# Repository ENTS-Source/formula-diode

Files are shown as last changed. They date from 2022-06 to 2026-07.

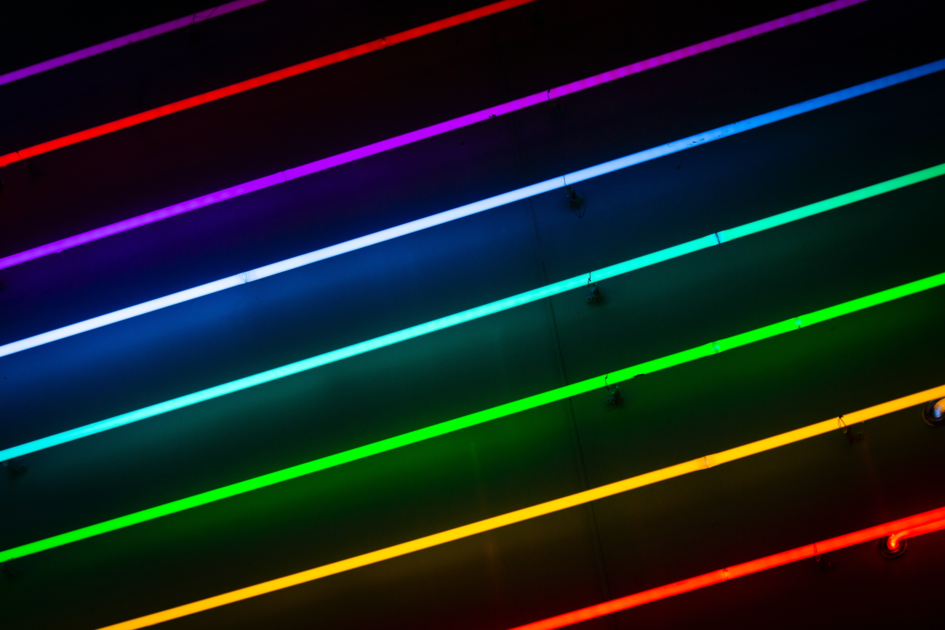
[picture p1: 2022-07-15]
pi-scoreboard/src/components/main/bg.jpg

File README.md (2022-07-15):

# led-race
Race each other on an LED strip, using an ESP8266

## Arduino libraries

* Regexp
* AsyncHTTPRequest_Generic
* ESP8266WiFi
* WiFiManager

## Running scoreboard

`npm install && npm start` in `pi-scoreboard`

Screenshot:


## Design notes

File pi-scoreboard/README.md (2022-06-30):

Created using https://www.electronforge.io/guides/framework-integration/react-with-typescript as a guide.

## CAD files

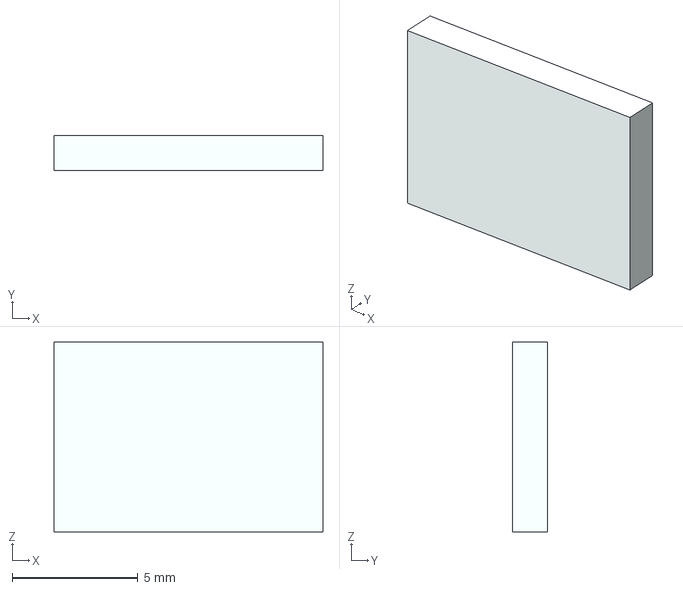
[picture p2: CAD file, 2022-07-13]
boards/kicad/Foorprints/IC_Microchip_MCP1825S-3302E_AB/eec.models/Microchip_-_MCP1825S-3302E/AB.step
10.7 x 1.40 x 7.55 mm

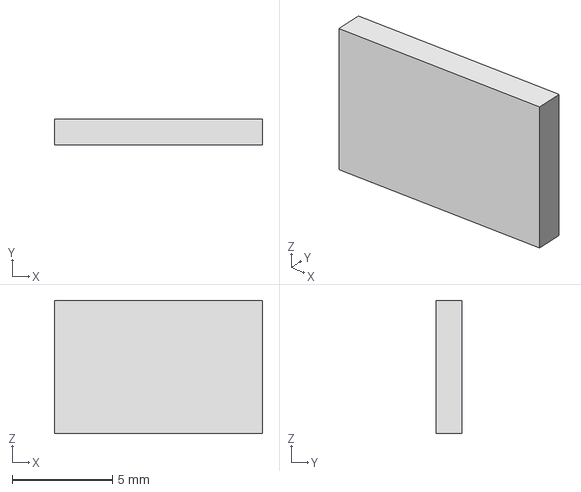
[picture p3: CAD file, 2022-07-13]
boards/kicad/Foorprints/IC_STMicroelectronics_LD1117V33C/eec.models/STMicroelectronics_-_LD1117V33C.step
10.4 x 1.30 x 6.65 mm

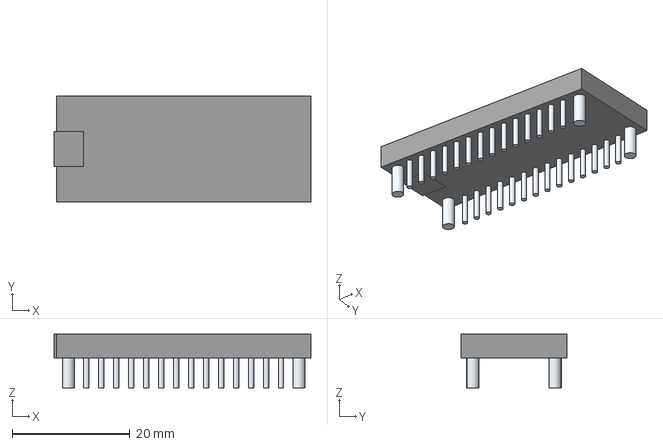
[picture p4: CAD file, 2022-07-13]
boards/kicad/Foorprints/LIB_Metro/2590/3D/2590.stp
43.6 x 18.0 x 9.10 mm
Leads x 32

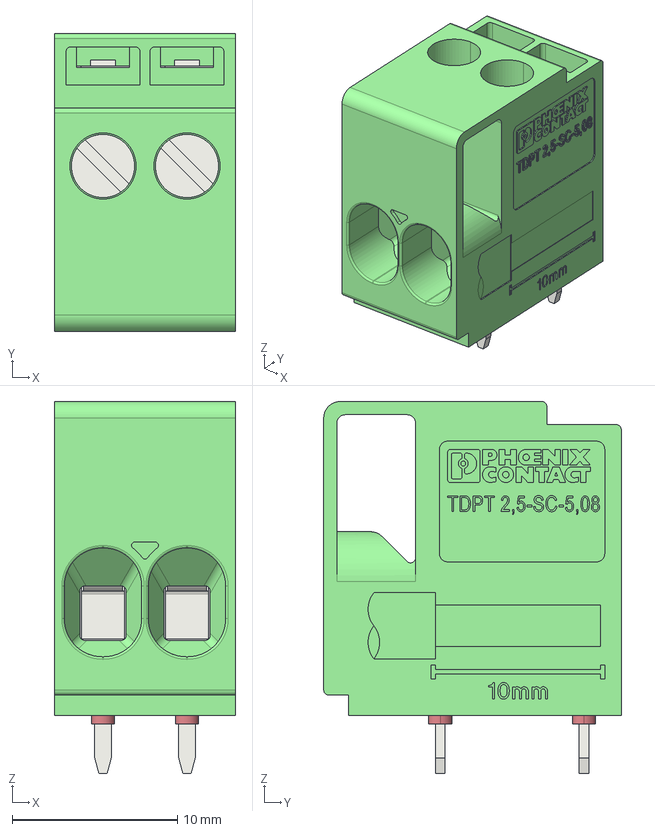
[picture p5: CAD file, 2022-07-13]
boards/kicad/Foorprints/LIB_1017491/1017491/3D/1017491.stp
11.0 x 18.0 x 22.5 mm
Bohrloch x 4
AC_MKDSN_2_5_Laengsschlitz x 2
KK_TDPT_Klemmhuelse x 2
LP_TDPT_2_5_SC_current_bar x 2
TDPT-2.5-2-SC-5.08-GEH

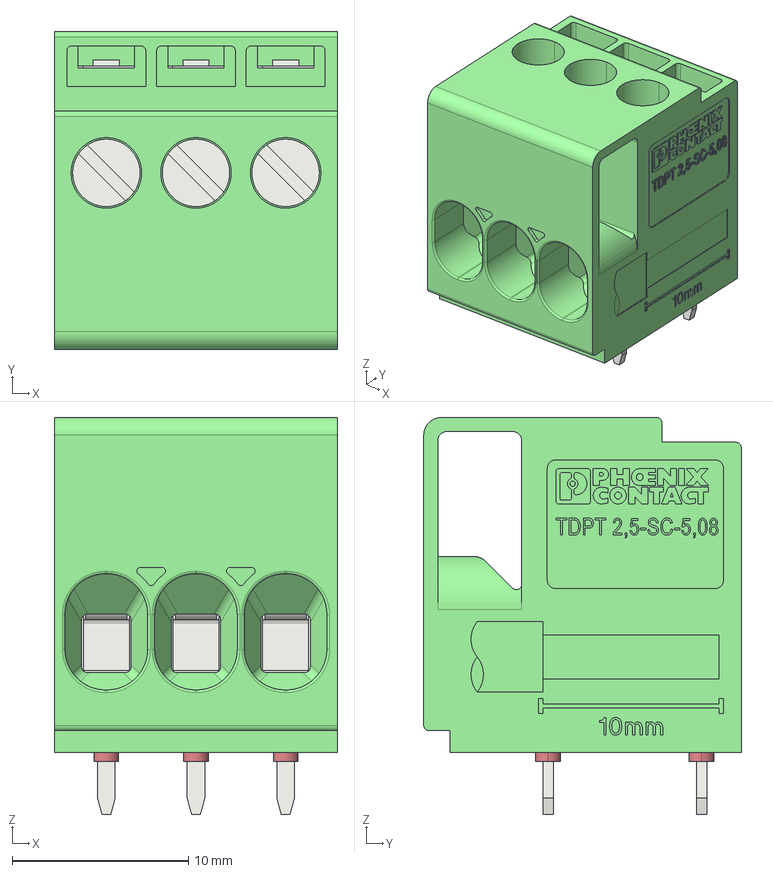
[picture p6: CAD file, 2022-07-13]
boards/kicad/Foorprints/LIB_1017492/1017492/3D/1017492.stp
16.0 x 18.0 x 22.5 mm
Bohrloch x 6
AC_MKDSN_2_5_Laengsschlitz x 3
KK_TDPT_Klemmhuelse x 3
LP_TDPT_2_5_SC_current_bar x 3
TDPT-2.5-3-SC-5.08-GEH

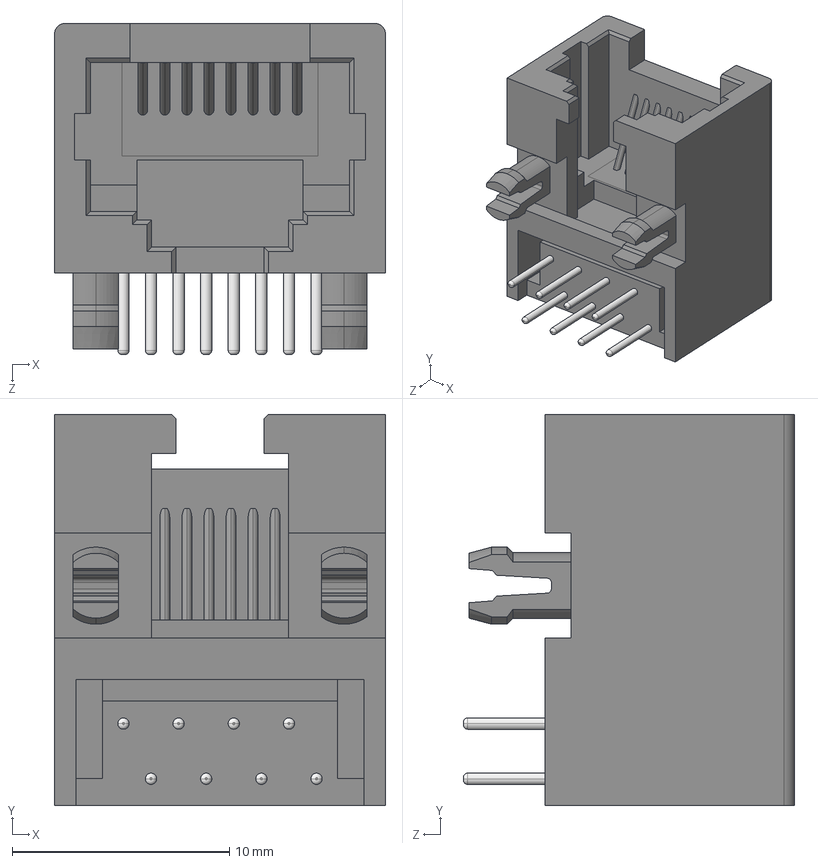
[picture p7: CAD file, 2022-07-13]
boards/kicad/Foorprints/LIB_54601-908WPLF/54601-908WPLF/3D/54601-908WPLF.stp
15.2 x 18.0 x 15.2 mm

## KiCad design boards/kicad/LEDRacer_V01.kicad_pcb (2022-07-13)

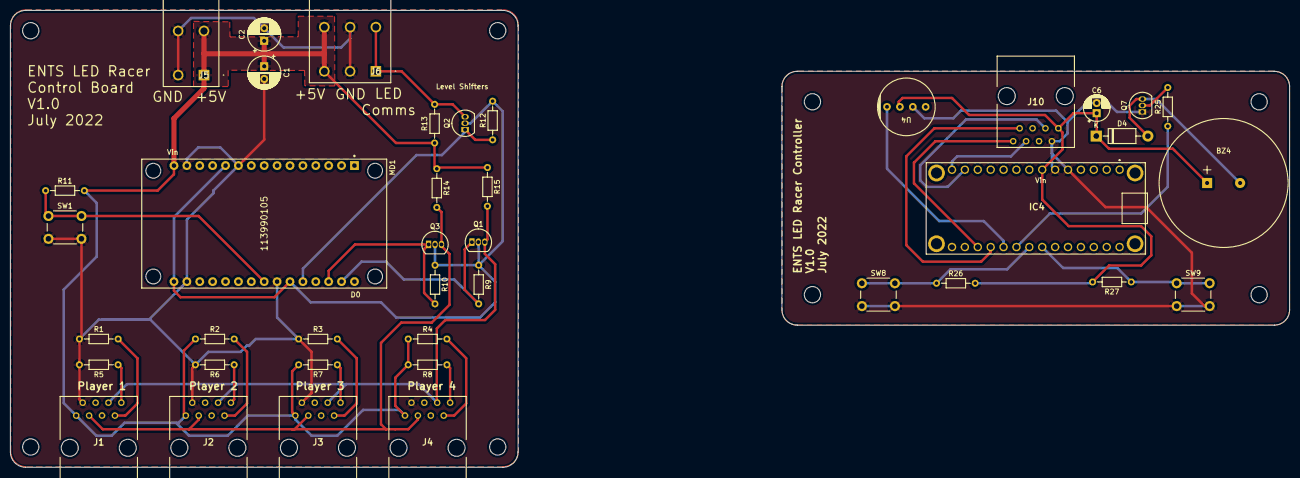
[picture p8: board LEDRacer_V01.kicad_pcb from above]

Board: 2 copper layers, 252.0 x 90.0 mm, 40 parts (0 on the bottom side), 28 nets.

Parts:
BZ4: Buzzer; WT1209
C1, C2: C_Polarized; CP_Radial_D6.3mm_P2.50mm
C6: C_Polarized; CP_Radial_D5.0mm_P2.00mm
D4: D; D_DO-41_SOD81_P10.16mm_Horizontal
IC4: 2590
J1, J2, J3, J4, J10: 54601-908WPLF; 54601908WPLF
J5: 1017491
J6: 1017492
MD1: 113990105; Seeed_Studio-113990105-MFG
Q1, Q2, Q3: TN0104N3-G; TO-92_Inline
Q7: Q_NPN_EBC; TO-92_Inline
R1, R2, R3, R4, R5, R6, R7, R8: 1k; R_Axial_DIN0204_L3.6mm_D1.6mm_P7.62mm_Horizontal
R9, R10, R14, R15: 4.7K; R_Axial_DIN0204_L3.6mm_D1.6mm_P7.62mm_Horizontal
R11, R12, R13, R26, R27: 4.7k; R_Axial_DIN0204_L3.6mm_D1.6mm_P7.62mm_Horizontal
R25: 1.5k; R_Axial_DIN0204_L3.6mm_D1.6mm_P7.62mm_Horizontal
SW1, SW8, SW9: SW_Push; SW_PUSH_6mm
U4: COM-12986; COM12986

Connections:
+3V3: MD1.11 (3V3), MD1.16 (3V3), MD1.25 (3V3), Q1.2 (G), Q2.2 (G), Q3.2 (G), R9.1, R10.1, R12.2
+5V: BZ4.1 (-), C1.1, C2.1, C6.1, D4.1 (K), IC4.7 (VIN), J1.1, J2.1, J3.1, J4.1, J5.1 (1.1), J5.2 (1.2), J6.5 (3.1), J6.6 (3.2), J10.1, MD1.15 (VIN), R2.1, R4.1, R7.2, R8.2, R11.2, R13.2, R14.1, R15.1, R26.2, R27.2, U4.2 (VDD)
/Button: MD1.23 (D5), R11.1, SW1.1
/Controller3/Button_1: IC4.21 (I/O_6), R26.1, SW8.1
/Controller3/Button_2: IC4.22 (I/O_7), R27.1, SW9.1
/Controller3/Buzzer: IC4.20 (I/O_5), R25.1
/Controller3/ID_1: IC4.18 (I/O_3), J10.7
/Controller3/ID_2: IC4.17 (I/O_2), J10.8
/Controller3/LED_Sig: IC4.19 (I/O_4), U4.1 (DIN)
/Controller3/SCL_HV: IC4.14 (A5), J10.6
/Controller3/SDA_HV: IC4.13 (A4), J10.3
/LED_COMM_HV: J6.1 (1.1), J6.2 (1.2), Q2.3 (D), R13.1
/LED_COMM_LV: MD1.26 (D4), Q2.1 (S), R12.1
/SCL_HV: J1.6, J2.6, J3.6, J4.6, Q1.3 (D), R15.2
/SCL_LV: MD1.29 (D1), Q1.1 (S), R9.2
/SDA_HV: J1.3, J2.3, J3.3, J4.3, Q3.3 (D), R14.2
/SDA_LV: MD1.28 (D2), Q3.1 (S), R10.2
GND: C1.2, C2.2, C6.2, IC4.5 (GND_1), IC4.6 (GND_2), J1.2, J2.2, J3.2, J4.2, J5.3 (2.1), J5.4 (2.2), J6.3 (2.1), J6.4 (2.2), J10.2, MD1.10 (GND), MD1.14 (GND), MD1.17 (GND), MD1.24 (GND), Q7.1 (E), R1.1, R3.1, R5.2, R6.2, SW1.2, SW8.2, SW9.2, U4.3 (VSS)
unnamed: BZ4.2 (+), D4.2 (A), Q7.3 (C)
unnamed: J1.7, R1.2
unnamed: J1.8, R5.1
unnamed: J2.7, R2.2
unnamed: J2.8, R6.1
unnamed: J3.7, R3.2
unnamed: J3.8, R7.1
unnamed: J4.7, R4.2
unnamed: J4.8, R8.1
unnamed: Q7.2 (B), R25.2

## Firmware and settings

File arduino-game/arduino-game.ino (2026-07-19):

#include <FastLED.h>
#include <EEPROM.h>
#include <Regexp.h>
#include <WiFiManager.h>
#include <Wire.h>
#include <ArduinoOTA.h>

// NodeMCU / ESP8266

/*
TODO:
- Fix NO_SCOREBOARD to actually work (also, make it configurable via web)
- Add world editor (ideally via web: add feature button, left+right to move down the track, up+down to make bigger and smaller)
- Easy/Medium/Hard levels (switchable from front button?)
- Make LED strip length web config (with visual so it can be easily measured)
- Try to remove I2C dependency to deal with PCB flexing issues
- Interrupt screensaver with controller buttons? (undecided)
*/

#define BTN_PIN D5 // TODO: Will we need to support multiple buttons?
#define SDA_PIN D2
#define SCL_PIN D1
#define WIRE_SPEED 100000
#define I2C_PLAYERS 4
#define STRIP_COUNT 1 // TODO: Support this being 2 (using logical strips)
#define MAX_LAPS 3 // TODO: Config val
#define LED_STRIP_PIN D4
//#define STRIP_LENGTH 325
//#define STRIP_LENGTH 385
#define MIN_STRIP_LENGTH 40
#define MAX_STRIP_LENGTH 600
#define WINNER_SHOWN_MS 2500
#define INIT_PLAYER_LENGTH 3
#define PHYSICS_ACCL 0.125 // Velocity added per button press
#define PHYSICS_FRICTION 0.017
#define GRAVITY_EFFECT 0.007
#define SPEED_BOOST_FACTOR 0.3
#define TAR_TRAP_FRICTION 0.18
#define TAR_TRAP_ACCL 0.06
#define CATCHUP_BOOST_ACCL 0.20
#define PHYSICS_MAX_VELOCITY 800000
#define PHYSICS_MIN_VELOCITY -2
#define PHYSICS_MS 5 // Time between physics checks
#define SCREENSAVER_WAIT_MS 120000 // 2 minutes
#define GAME_TIMEOUT_MS 30000 // 30 seconds
#define COUNT_MODE_WAIT_MS 5000 // 5 seconds
#define AUTO_RAND_MIN 0
#define AUTO_RAND_MAX 1000
#define AUTO_THRESHOLD 50 // Note: debounce is typically 10ms, so 15/1000 is essentially saying "every 15ms, trigger"
#define AUTO_PRESSES_PER 1
#define AUTO_PLAYERS 2
#define RENDER_INTERVAL 14

#define NOT_CONNECTED_PIN D6
#define CONF_EEPROM_SIZE 512
#define CONF_LENGTH_ADDR 128 // start a bit high to give wifimanager some room
#define BTN_OPEN HIGH
#define BTN_CLOSED LOW
#define BTN_DEBOUNCE_MS 10
#define I2C_PLAYER_START 0 // address
#define TOHOST_LENGTH 2  // btn 1 presses & btn 2 presses, 2 bytes
#define FROMHOST_ASSIGN 0x10
#define FROMHOST_RESET 0x11
#define TRAFFIC_START 7 // address; +1 from bottom, for aesthetics. Must be at least 6
#define NO_WINNER -1
#define NW_STATUS_LED 4
#define WIRE_PING_MS 5000
#define GRAVITY_ENABLED B00000001
#define SPEED_BOOST_ENABLED B00000100
#define SLOPE_FORWARD B00000010
#define SLOPE_BACKWARD B00000000 // inverse of forward
#define TAR_TRAP_ENABLED B00001000

int featuresRange[][3] = {
  // 2022
//  {272, 38, GRAVITY_ENABLED | SLOPE_BACKWARD},
//  {310, 35, GRAVITY_ENABLED | SLOPE_FORWARD},

  // 2025-1
//  {265, 5, SPEED_BOOST_ENABLED},
//  {45, 5, SPEED_BOOST_ENABLED},

  // 2025-2
  {249, 5, TAR_TRAP_ENABLED},
  {307, 5, SPEED_BOOST_ENABLED},
  {119, 5, SPEED_BOOST_ENABLED},
//  {11, 15, SPEED_BOOST_ENABLED},
};

struct PlayerState {
  float velocity;
  float position;
  int location; // int position
  int length;
  CRGB color;

  int unhandledPresses;
  long lastPhysics;

  long finishMs;
  long lastLapFinishMs;
  bool isConnected;
};

int stripLength = MIN_STRIP_LENGTH;
CRGB leds[MAX_STRIP_LENGTH * STRIP_COUNT];
byte stripMap[MAX_STRIP_LENGTH * STRIP_COUNT];
long startTimeMs = 0;
long lightsStartMs = 0;
long endMs = 0;
long lastGameEnd = 0;
int winnerNum = NO_WINNER;
bool inGame = false;
bool isAutomatedGame = false;
bool btnDownTrigger = false;
bool btnUpTrigger = false;
bool btnPressed = false;
long lastWireScan = 0;
long lastRender = 0;
long lastPress = 0;
bool countingMode = false;
long countModeStartTimeout = 0;
long lastCountModeChange = 0;

CRGB TRAFFIC_RED = CRGB(255, 0, 0);
CRGB TRAFFIC_YELLOW = CRGB(239, 83, 0);
CRGB TRAFFIC_GREEN = CRGB(0, 132, 5);

CRGB SPEED_BOOST_COLOR = CRGB(255, 170, 0);
CRGB TAR_TRAP_COLOR = CRGB(46, 0, 74);

CRGB colors[I2C_PLAYERS] = {
  CRGB::Blue,
  CRGB::Red,
  CRGB::Green,
  CRGB::Orange,
};
PlayerState players[I2C_PLAYERS] = {
  PlayerState{},
  PlayerState{},
  PlayerState{},
  PlayerState{},
};

void setup() {
  randomSeed(analogRead(NOT_CONNECTED_PIN));
  Serial.begin(115200);
  gnetSetup();
  confSetup();
  ledSetup(false);
  trakSetup();
  netSetup();

  for (int i = 0; i < I2C_PLAYERS; i++) {
    playerReset(players[i]);
    players[i].color = colors[i];
    Serial.print("Player ");
    Serial.print(i);
    Serial.print(" is ");
    printColor(colors[i]);
    Serial.println();
  }

  gnetScan();
  gnetResetAll();
  updatePlayerIds();
}

void loop() {
  ArduinoOTA.handle();

  bool doReset = trakUpdate();
  if (doReset || ((!inGame || isAutomatedGame) && lightsStartMs == 0 && (millis() - lastWireScan) > WIRE_PING_MS)) {
    lastWireScan = millis();
    gnetScan();
    gnetResetAll();
    updatePlayerIds();
  }
  gnetUpdate();
  if (countingMode) {
    int newLength = stripLength;
    lastGameEnd = millis(); // avoid screensaver
    newLength += players[0].unhandledPresses;
    newLength -= players[1].unhandledPresses;
    // Serial.print("Strip length: ");
    // Serial.print(stripLength);
    // Serial.print("     New strip length: ");
    // Serial.print(newLength);
    // Serial.print("     player0 presses: ");
    // Serial.print(players[0].unhandledPresses);
    // Serial.print("     player1 presses: ");
    // Serial.println(players[1].unhandledPresses);
    players[0].unhandledPresses = 0;
    players[1].unhandledPresses = 0;
    if (newLength != stripLength) {
      confWriteInt(CONF_LENGTH_ADDR, newLength);
      confWrite();
      ledSetup(true); // this will clear the old length and new length for us
      trakCountStrip();
    }
    if (btnPressed && (millis() - lastCountModeChange) > COUNT_MODE_WAIT_MS) {
      Serial.println("Exiting counting mode");
      countingMode = false;
      countModeStartTimeout = millis();
      lastCountModeChange = millis();
    }
  } else if (!inGame && !countingMode && (millis() - lastCountModeChange) > COUNT_MODE_WAIT_MS) {
    if (countModeStartTimeout == 0 && btnDownTrigger) {
      Serial.println("Starting count mode wait");
      countModeStartTimeout = millis();
    } else if (!btnPressed) {
      // Serial.println("Resetting count mode wait");
      countModeStartTimeout = 0;
    } else if ((millis() - countModeStartTimeout) > COUNT_MODE_WAIT_MS) {
      Serial.println("Entering counting mode");
      countingMode = true;
      lastCountModeChange = millis();
    }
  }
}

void updatePlayerIds() {
  for (int i = 0; i < I2C_PLAYERS; i++) {
    gnetUpdateColor(i, players[i].color.r, players[i].color.g, players[i].color.b);
  }
}

void ledSetup(bool andClear) {
  if (andClear) {
    trakClear(); // clear old size
    trakRender();
  }

  stripLength = confReadInt(CONF_LENGTH_ADDR);
  if (stripLength <= MIN_STRIP_LENGTH) {
    stripLength = MIN_STRIP_LENGTH;
  }
  if (stripLength > MAX_STRIP_LENGTH) { // also avoids empty EEPROM having 0xFFFF values (65535)
    stripLength = MAX_STRIP_LENGTH;
  }
  Serial.print("Strip length: ");
  Serial.println(stripLength);
  
  if (andClear) {
    trakClear(); // clear new size (if larger/different)
    trakRender();
  }

  for (int i = 0; i < (stripLength * STRIP_COUNT); i++) {
    stripMap[i] = 0;
  }

  int featureRows = sizeof(featuresRange) / sizeof(featuresRange[0]);
  for (int i = 0; i < featureRows; i++) {
    int startIdx = featuresRange[i][0];
    int lengthIdx = featuresRange[i][1];
    byte flags = featuresRange[i][2];
    for (int j = startIdx; j <= (startIdx + lengthIdx); j++) {
      if (j > (stripLength * STRIP_COUNT)) {
        continue;
      }
      stripMap[j] = flags;
    }
  }
  
  trakSetupForDrawPlayers();
}

// ---------------------------------------------------------------
// ---- PLAYERS
// ===============================================================

void playerPhysics(PlayerState &player) {
  if (!player.isConnected) {
    return;
  }
  if (player.finishMs > 0) {
    return; // they're done the race
  }

  // Check if player is behind
  bool behind = false;
  uint8_t numFinished = 0;
  for (int i = 0; i < I2C_PLAYERS; i++) {
    PlayerState pl = players[i];
    if (pl.finishMs > 0 || !pl.isConnected) {
      numFinished++;
      continue; // skip players that are already done
    }
    int diff = player.location - pl.location;
    if (diff <= (-1 * stripLength)) { // 1 full lap behind
      behind = true;
    }
  }
  // Serial.print("Behind? ");
  // Serial.print(behind);
  if (!behind && (I2C_PLAYERS - numFinished) == 1) {
    behind = true;
  }
  // Serial.print("   Still? ");
  // Serial.println(behind);

  int relPos = (player.location + player.length) % stripLength;
  bool tarTrap = (stripMap[relPos] & TAR_TRAP_ENABLED) != 0;
  for (int i = 0; i < player.unhandledPresses; i++) {
    if (behind) {
      player.velocity += CATCHUP_BOOST_ACCL;
    }
    lastPress = millis();
    if (tarTrap) {
      player.velocity += TAR_TRAP_ACCL;
    } else {
      player.velocity += PHYSICS_ACCL;
    }
  }
  player.unhandledPresses = 0;

  if ((millis() - player.lastPhysics) < PHYSICS_MS) {
    return; // done with physics for now
  }
  player.lastPhysics = millis();

  if (player.velocity > PHYSICS_MAX_VELOCITY) {
    player.velocity = PHYSICS_MAX_VELOCITY;
  }

  // Move vehicle
  float friction = PHYSICS_FRICTION;
  if (tarTrap) {
    friction = TAR_TRAP_FRICTION;
  }
  player.velocity -= player.velocity * friction;
  if (player.velocity < PHYSICS_MIN_VELOCITY) {
    player.velocity = PHYSICS_MIN_VELOCITY;
  }
  player.position += player.velocity;
  player.location = round(player.position); // int location

  // Gravity, front wheel drive
  relPos = (player.location + player.length) % stripLength;
  if ((stripMap[relPos] & GRAVITY_ENABLED) != 0) {
    float effect = GRAVITY_EFFECT;
    if ((stripMap[relPos] & SLOPE_FORWARD) == 0) {
      // means we're sloping backwards
      effect = effect * -1;
    }
    player.velocity += effect;
    player.position += player.velocity;
  }
  if ((stripMap[relPos] & SPEED_BOOST_ENABLED) != 0) {
    player.velocity += SPEED_BOOST_FACTOR;
    player.position += player.velocity;
//    stripMap[relPos] = (stripMap[relPos] & ~SPEED_BOOST_ENABLED);
  }

  // Last minute check on position
  if (player.position < 0) {
    player.position = 0;
  }
  player.location = round(player.position);
}

void playerReset(PlayerState &player) {
  player.length = INIT_PLAYER_LENGTH;
  player.position = 0;
  player.location = 0;
  player.velocity = 0;
  player.finishMs = 0;
  player.lastLapFinishMs = 0;
  player.unhandledPresses = 0;
}

// ---------------------------------------------------------------
// ---- TRACK
// ===============================================================

void trakSetup() {
  trakClear();
  trakRender();
  FastLED.addLeds<WS2812B, LED_STRIP_PIN, GRB>(leds, MAX_STRIP_LENGTH);
}

// Primary loop
// ======================================

bool trakUpdate() {
  bool shouldReset = false;
  btnUpdate();

  if (countingMode) {
    return shouldReset; // nothing to do except update the button
  }

  trakClear();

  if (!inGame) {
    if (winnerNum != NO_WINNER) {
      long timeDiff = millis() - endMs;
      if (timeDiff < WINNER_SHOWN_MS) {
        trakDrawWinner();
      } else {
        winnerNum = NO_WINNER;
        endMs = 0;
        lastGameEnd = millis();

        if (isAutomatedGame) {
          lastGameEnd = 0; // allow another automated game to start right away
          shouldReset = true;
        }
      }
    } else if (lightsStartMs > 0) {
      if (isAutomatedGame) {
        leds[TRAFFIC_START + 6] = CRGB::Purple;
        leds[TRAFFIC_START + 5] = CRGB::Purple;
      }
      
      leds[TRAFFIC_START - 0] = TRAFFIC_RED;
      leds[TRAFFIC_START - 1] = TRAFFIC_RED;

      if ((millis() - lightsStartMs) >= 1000) {
        leds[TRAFFIC_START - 2] = TRAFFIC_YELLOW;
        leds[TRAFFIC_START - 3] = TRAFFIC_YELLOW;
      }

      if ((millis() - lightsStartMs) >= 2000) {
        for (int i = 0; i < 6; i++) {
          leds[TRAFFIC_START - i] = TRAFFIC_GREEN;
        }
      }

      if ((millis() - lightsStartMs) >= 2400) {
        shouldReset = true;
        inGame = true;
        lightsStartMs = 0;
        startTimeMs = millis();

        int nPlayers = 0;
        for (int i = 0; i < I2C_PLAYERS; i++) {
          playerReset(players[i]);
          if (players[i].isConnected) {
            nPlayers++;
          }
        }
      }
    } else if ((millis() - lastGameEnd) > SCREENSAVER_WAIT_MS) {
      isAutomatedGame = true;
      Serial.println("Screensaver");
      
      lightsStartMs = millis();
      shouldReset = true;
    }
  } else {
    trakUpdatePlayers();
    trakDrawBoosts();
    trakDrawPlayers();
    if (!isAutomatedGame && (millis() - lastPress) > GAME_TIMEOUT_MS) {
      isAutomatedGame = true;
      lastGameEnd = 0; // enter screensaver immediately
    }
  }
  
  if (btnUpTrigger) {
    // Interrupt current game and start a new one
    isAutomatedGame = false;    
    lightsStartMs = millis();
    shouldReset = true;
    lastPress = millis();
    inGame = false;
  }

  if ((millis() - lastRender) >= RENDER_INTERVAL) {
    lastRender = millis();
    trakRender();
  }
  return shouldReset;
}

// Game functions
// ======================================

void trakUpdatePlayers() {
  bool allDone = true;
  for (int i = 0; i < I2C_PLAYERS; i++) {
    if (isAutomatedGame) {
      players[i].isConnected = (i < AUTO_PLAYERS);
    }
    
    if (!players[i].isConnected) {
      continue;
    }
    if (players[i].finishMs > 0) {
      continue; // already finished all laps (don't adjust lap times)
    }

    if (isAutomatedGame && random(AUTO_RAND_MIN, AUTO_RAND_MAX) <= AUTO_THRESHOLD) {
      players[i].unhandledPresses += AUTO_PRESSES_PER;
    }

    int oldLaps = players[i].location / stripLength;
    playerPhysics(players[i]);
    int newLaps = players[i].location / stripLength;

    if (newLaps != oldLaps) {
      long lastLapMs = players[i].lastLapFinishMs;
      if (lastLapMs == 0) {
        lastLapMs = startTimeMs;
      }
      long lapTime = millis();
      players[i].lastLapFinishMs = lapTime;
    }

    if ((players[i].location / stripLength) >= MAX_LAPS) {
      players[i].finishMs = millis();
    }

    allDone = allDone && (players[i].finishMs > 0);
  }

  if (allDone) {
    inGame = false;
    endMs = millis();
    winnerNum = NO_WINNER;
    for (int i = 0; i < I2C_PLAYERS; i++) {
      if (!players[i].isConnected) {
        continue;
      }
      if (winnerNum == NO_WINNER || players[winnerNum].finishMs > players[i].finishMs) {
        winnerNum = i;
      }
    }
  }
}

// Render functions
// ======================================

void trakClear() {
  for (int i = 0; i < (stripLength * STRIP_COUNT); i++) {
    leds[i] = CRGB::Black;
  }
}

void trakCountStrip() {
  for (int i = 0; i < (stripLength * STRIP_COUNT); i++) {
    leds[i] = SPEED_BOOST_COLOR;
  }
  trakRender();
}

void trakDrawWinner() {
  for (int i = 0; i < (stripLength * STRIP_COUNT); i++) {
    leds[i] = players[winnerNum].color;
  }
}

void printColor(CRGB color) {
  Serial.print(color.r);
  Serial.print(",");
  Serial.print(color.g);
  Serial.print(",");
  Serial.print(color.b);
}

uint8_t* positionMap = nullptr;
bool* didTrapOverlay = nullptr;

void trakSetupForDrawPlayers() {
  if (positionMap != nullptr) {
    delete[] positionMap;
    positionMap = nullptr;
  }
  if (didTrapOverlay != nullptr) {
    delete[] didTrapOverlay;
    didTrapOverlay = nullptr;
  }
  positionMap = new uint8_t[stripLength * STRIP_COUNT];
  didTrapOverlay = new bool[stripLength * STRIP_COUNT];
}

void trakDrawPlayers() {
  // Figure out where each player is an render them into the LEDs
  for (int i = 0; i < (stripLength * STRIP_COUNT); i++) {
    positionMap[i] = 0;
    didTrapOverlay[i] = false;
  }
  for (int i = 0; i < I2C_PLAYERS; i++) {
    if (!players[i].isConnected) {
      continue;
    }
    if (players[i].finishMs > 0) {
      continue; // don't render: they're done
    }

    int startPos = players[i].location % stripLength;
    for (int j = 0; j < players[i].length; j++) {
      int targetLoc = startPos + j;
      int maxStripPos = stripLength * STRIP_COUNT;
      if (targetLoc >= maxStripPos) {
        targetLoc = (targetLoc - maxStripPos); // overrun
      }
      positionMap[targetLoc]++;
//      Serial.print("@@ Draw ");
//      Serial.print(targetLoc);
//      Serial.print(" curr:");
//      printColor(leds[targetLoc]);
//      Serial.print(" plyr:");
//      printColor(players[i].color);
        if ((stripMap[targetLoc] & TAR_TRAP_ENABLED) != 0 && !didTrapOverlay[targetLoc]) {
          leds[targetLoc] = CRGB(0, 0, 0);
          didTrapOverlay[targetLoc] = true;
        }
        leds[targetLoc] = CRGB(
          leds[targetLoc].r + players[i].color.r,
          leds[targetLoc].g + players[i].color.g,
          leds[targetLoc].b + players[i].color.b
        );
//      Serial.print(" res:");
//      printColor(leds[targetLoc]);
//      Serial.println();
    }
  }

  // Mix colors
  for (int i = 0; i < (stripLength * STRIP_COUNT); i++) {
    uint8_t mapHeight = positionMap[i];
    if (mapHeight > 1) {
      leds[i] = CRGB(
        leds[i].r / mapHeight,
        leds[i].g / mapHeight,
        leds[i].b / mapHeight
      );
    }
  }
}

void trakDrawBoosts() {
  for (int i = 0; i < (stripLength * STRIP_COUNT); i++) {
    if ((stripMap[i] & SPEED_BOOST_ENABLED) != 0) {
      leds[i] = SPEED_BOOST_COLOR;
    }
    if ((stripMap[i] & TAR_TRAP_ENABLED) != 0) {
      leds[i] = TAR_TRAP_COLOR;
    }
  }
}

void trakRender() {
  FastLED.show();
}

// ---------------------------------------------------------------
// ---- GAME NET
// ===============================================================

void gnetSetup() {
  Wire.setClock(WIRE_SPEED);
  Wire.begin(SDA_PIN, SCL_PIN);
}

void gnetUpdate() {
  for (int i = 0; i < I2C_PLAYERS; i++) {
    if (!players[i].isConnected) {
      continue;
    }

    byte addr = I2C_PLAYER_START + i;
    Wire.requestFrom(addr, TOHOST_LENGTH);
    byte pos = 0;
    while (Wire.available()) {
      byte b = Wire.read();
      if (pos >= TOHOST_LENGTH) {
        continue;
      }

      if (pos == 0) {
        players[i].unhandledPresses += b;
      } else if (pos == 1) {
        // Secondary button not used
      }

      pos++;
    }
  }
}

void gnetScan() {
  for (int i = 0; i < I2C_PLAYERS; i++) {
    byte addr = I2C_PLAYER_START + i;
    Wire.beginTransmission(addr);
    byte err = Wire.endTransmission();
    if (err == 0) {
      Serial.print(i);
      Serial.println(" is connected to I2C");
      players[i].isConnected = true;
    } else {
      Serial.print(i);
      Serial.print(" failed to connect on I2C with error ");
      Serial.println(err);
      players[i].isConnected = false;
    }
  }
}

void gnetUpdateColor(int playerNum, byte r, byte g, byte b) {
  if (!players[playerNum].isConnected) {
    return;
  }

  Wire.beginTransmission(I2C_PLAYER_START + playerNum);
  byte msg[4] = {FROMHOST_ASSIGN, r, g, b};
  Wire.write(msg, 4);
  Wire.endTransmission();
}

void gnetResetController(int playerNum) {
  if (!players[playerNum].isConnected) {
    return;
  }

  Wire.beginTransmission(I2C_PLAYER_START + playerNum);
  byte msg[1] = {FROMHOST_RESET};
  Wire.write(msg, 1);
  Wire.endTransmission();
}

void gnetResetAll() {
  for (int i = 0; i < I2C_PLAYERS; i++) {
    gnetResetController(i);
  }
}

// ---------------------------------------------------------------
// ---- BUTTON
// ===============================================================

int btnLastState = BTN_OPEN;
int btnLastRead = BTN_OPEN;
int btnLastReadMs = 0;

void btnUpdate() {
  btnDownTrigger = false;
  btnUpTrigger = false;

  int val = digitalRead(BTN_PIN);
  if (val != btnLastRead) {
    btnLastRead = val;
    btnLastReadMs = millis();
  }
  if ((millis() - btnLastReadMs) > BTN_DEBOUNCE_MS) {
    if (val != btnLastState) {
      btnLastState = val;
      if (btnLastState == BTN_CLOSED) {
        btnPressed = true;
        btnDownTrigger = true;
      } else {
        btnPressed = false;
        btnUpTrigger = true;
      }
    }
  }
}

void btnUpdateBlocking() {
  btnUpdate();
  delay(BTN_DEBOUNCE_MS + 5);
  btnUpdate();
}

// ---------------------------------------------------------------
// ---- CONFIG
// ===============================================================

void confSetup() {
  EEPROM.begin(CONF_EEPROM_SIZE);
}

void confRead() {
}

void confWrite() {
  EEPROM.commit();
}

void confClear() {
  confWrite();
}

void confReadString(int addr, int len, char str[]) {
  for (int i = 0; i < len; i++) {
    str[i] = char(confReadByte(addr + i));
  }
}

void confWriteString(int addr, int len, char val[]) {
  for (int i = 0; i < len; i++) {
    confWriteByte(addr + i, val[i]);
  }
}

int confReadInt(int addr) {
  byte part1 = confReadByte(addr);
  byte part2 = confReadByte(addr + 1);

  return (part1 << 8) + part2;
}

void confWriteInt(int addr, int val) {
  confWriteByte(addr, val >> 8);
  confWriteByte(addr + 1, val & 0xFF);
}

byte confReadByte(int addr) {
  return EEPROM.read(addr);
}

void confWriteByte(int addr, byte val) {
  EEPROM.write(addr, val);
}

// ---------------------------------------------------------------
// ---- NETWORK
// ===============================================================

WiFiManager wm;
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

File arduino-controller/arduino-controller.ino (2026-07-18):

#include <FastLED.h>
#include "Button.h"
#include "VibrationMotor.h"
#include "IDLED.h"
#include "GameNet.h"

// Metro Mini / Arduino Uno

#define NUM_PIN_LOW 2
#define NUM_PIN_HIGH 3
#define HARDCODE_PLAYER_NUM 1 // set negative to autodetect, zero or positive to force that number

Button* accl;
VibrationMotor* motor;
IDLED* led;
GameNet* gamenet;

byte lastR = 0;
byte lastG = 0;
byte lastB = 0;

void setup() {
  pinMode(NUM_PIN_LOW, INPUT);
  pinMode(NUM_PIN_HIGH, INPUT);
  
  Serial.begin(115200);

  byte playerNum = 0;
  if (HARDCODE_PLAYER_NUM < 0) {
    Serial.println("Reading player number");
    if (digitalRead(NUM_PIN_LOW) == HIGH) {
      playerNum = playerNum | B00000001;
    }
    if (digitalRead(NUM_PIN_HIGH) == HIGH) {
      playerNum = playerNum | B00000010;
    }
  } else {
    Serial.println("Using hardcoded player number");
    playerNum = HARDCODE_PLAYER_NUM;
  }
  Serial.print("Player num: ");
  Serial.println(playerNum);
  
  gamenet = new GameNet(playerNum);
  accl = new Button(6);
  motor = new VibrationMotor(5);
  led = new IDLED();
  led->setColor(0, 0, 0);
}

void loop() {
  motor->update();
  accl->update();
  if (accl->isDownTrigger) {
//    motor->onForMs(1000);
    gamenet->acclBtnPresses++;
    Serial.println("Press");
  }
  checkLed();
  if (gamenet->checkResetFlag()) {
    Serial.println("Handling reset");
    gamenet->acclBtnPresses = 0;
    gamenet->secondBtnPresses = 0;
//    motor->off();
  }
}

void checkLed() {
  if (lastR == gamenet->idR && lastG == gamenet->idG && lastB == gamenet->idB) {
    return;
  }

  lastR = gamenet->idR;
  lastG = gamenet->idG;
  lastB = gamenet->idB;
  led->setColor(lastR, lastG, lastB);
  Serial.print("Set LED ");
  Serial.print(lastR);
  Serial.print(",");
  Serial.print(lastG);
  Serial.print(",");
  Serial.print(lastB);
  Serial.println();
}

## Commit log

2022-04-11 Initial rework of engine
    [arduino-game.ino]
2022-04-16 Add basics for a controller board
2022-05-23 Move controllers to I2C bus
2022-07-12 Convert button class to a proper struct
2022-07-13 Add circuit board stuff
    [1017491.stp, 1017492.stp, 2590.stp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]
2022-07-13 Make the code run again and add debugging
    Outstanding issues: scoreboard IP is getting corrupted (use cstrings?) and it crashes on game end.
    [arduino-game.ino]
2022-07-14 Fix overrun on LEDs array (memory corruption)
    [arduino-game.ino]
2022-07-15 Wire up the scoreboard
2022-07-16 Ping i2c to try and reduce disconnects
2022-07-16 Reduce impact of renders on app loop when scaled up to 300 LEDs
2022-07-16 Scan for i2c during screensaver
2022-09-22 Disable motor control
2022-09-22 Fix ID LED for boards
2022-09-22 Add track specific values and speed boosts
2026-07-18 Move LED setup into setup function
2026-07-19 Impose a minimum strip length to avoid out of range errors
    [arduino-game.ino]
2026-07-19 Fix a few performance bugs
    [arduino-game.ino]
2026-07-19 Always have button start a new game
